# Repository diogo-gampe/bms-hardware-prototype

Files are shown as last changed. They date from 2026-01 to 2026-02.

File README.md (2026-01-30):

## Desenvolvimento em KICAD de placa de avaliação do CI da Texas Instrumets BQ769x2 para monitoramento e proteção de batérias de íon-lítio 3S-16S.

## Changelog

12/12/25
- Separa folha de monitoramento, folha de proteção e folha raiz
- (Folha raiz)Adiciona conector para resistores shunt de simulação de células
- (Folha de monitoramento) Adiciona botão de WAKE no pino TS2 do CI e jumper para conectar termistor externo ao pino TS2
- (Folha de monitoramento) Adiciona conector para monitorar externamente tensões geradas por regulador interno do CI em REG1 e REG2.
- (Folha de proteção) Adiciona componentes para circuito de disparo de fusível controlável
- (Folha de proteção) Adiciona componentes para circuito de pré-carga/descarga
- (Folha de proteção) Adciona componentes para proteção de conexão com polaridade reversa

18/12/25
- Adiciona diretório com simulações de LTSpice
28/01/25
- Adiciona footprints finais, com base na lista de componentes fornecidas ao pessoal do SENAI
- Posiciona Net-Tie entre terminal negativo da bateria e tensão de referência dos CIs para isolar caminhos de alta corrente
30/01/25
- Posiciona footprints de testpoints para medições de sinais chave para testes. 
- Ajusta posicionamento de regiões de alta corrente.

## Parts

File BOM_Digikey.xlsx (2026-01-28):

Reference | Value | Qty | Digikey Link | Manufacturer_Part_Number
 | STM32H745ZIT3 | 5 | https://www.digikey.ca/en/products/detail/stmicroelectronics/STM32H745ZIT3/11591192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 | STM32H745ZIT3
 | BQ76972PFBR | 5 | https://www.digikey.ca/en/products/detail/texas-instruments/BQ7697202PFBR/22077512 | BQ7697202PFBR
U2 | BQ7695202PFBR | 5 | https://www.digikey.ca/en/products/detail/texas-instruments/BQ7695202PFBR/14123974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 | BQ7695202PFBR
 | TJA1044BT/0Z | 5 | https://www.digikey.ca/en/products/detail/nxp-usa-inc/TJA1044BT-0Z/19200494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 | TJA1044BT/0Z
C47 | 100pF | 5 | https://www.digikey.ca/en/products/detail/johanson-dielectrics-inc/VPDD102W101K1GV001E/2236983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 | VPDD102W101K1GV001E
C33 | 100pF | 5 | https://www.digikey.ca/en/products/detail/johanson-dielectrics-inc/VPDD102W101K1GV001E/2236983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 | VPDD102W101K1GV001E
SW1 | SW_DIP_x01 | 5 | https://www.digikey.ca/en/products/detail/adam-tech/SW-T3-1A-A-A3-S1/15284460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 | SW-T3-1A-A-A3-S1
D6 | LED | 5 | https://www.digikey.ca/en/products/detail/lumex-opto-components-inc/SML-LX1210IGC-TR/229144 | SML-LX1210IGC-TR
Q8 | Q_PMOS_GSD | 5 | https://www.digikey.ca/en/products/detail/vishay-siliconix/SI3437DV-T1-GE3/2441596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 | SI3437DV-T1-GE3
Q7 | Q_PMOS_GSD | 5 | https://www.digikey.ca/en/products/detail/vishay-siliconix/SI3437DV-T1-GE3/2441596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 | SI3437DV-T1-GE3
J5 | Conn_02x08_Odd_Even | 5 | https://www.digikey.ca/en/products/detail/sullins-connector-solutions/SBH11-PBPC-D08-ST-BK/1990064 | SBH11-PBPC-D08-ST-BK
R27 | 7.5k | 5 | https://www.digikey.ca/en/products/detail/stackpole-electronics-inc/RNCP1206FTD7K50/2240366 | RNCP1206FTD7K50
R59 | 100 | 5 | https://www.digikey.ca/en/products/detail/yageo/RC1206FR-07100RL/728491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 | RC1206FR-07100RL
R57 | 100 | 5 | https://www.digikey.ca/en/products/detail/yageo/RC1206FR-07100RL/728491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 | RC1206FR-07100RL
R55 | 100 | 5 | https://www.digikey.ca/en/products/detail/yageo/RC1206FR-07100RL/728491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 | RC1206FR-07100RL
R65 | 20 | 5 | https://www.digikey.ca/en/products/detail/yageo/RC1206FR-0720RL/728671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 | RC1206FR-0720RL
R64 | 20 | 5 | https://www.digikey.ca/en/products/detail/yageo/RC1206FR-0720RL/728671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 | RC1206FR-0720RL
R63 | 20 | 5 | https://www.digikey.ca/en/products/detail/yageo/RC1206FR-0720RL/728671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 | RC1206FR-0720RL
R36 | 20 | 5 | https://www.digikey.ca/en/products/detail/yageo/RC1206FR-0720RL/728671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 | RC1206FR-0720RL
R21 | 20 | 5 | https://www.digikey.ca/en/products/detail/yageo/RC1206FR-0720RL/728671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 | RC1206FR-0720RL
R20 | 20 | 5 | https://www.digikey.ca/en/products/detail/yageo/RC1206FR-0720RL/728671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 | RC1206FR-0720RL
R19 | 20 | 5 | https://www.digikey.ca/en/products/detail/yageo/RC1206FR-0720RL/728671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 | RC1206FR-0720RL
R18 | 20 | 5 | https://www.digikey.ca/en/products/detail/yageo/RC1206FR-0720RL/728671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 | RC1206FR-0720RL
R17 | 20 | 5 | https://www.digikey.ca/en/products/detail/yageo/RC1206FR-0720RL/728671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 | RC1206FR-0720RL
R16 | 20 | 5 | https://www.digikey.ca/en/products/detail/yageo/RC1206FR-0720RL/728671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 | RC1206FR-0720RL
R15 | 20 | 5 | https://www.digikey.ca/en/products/detail/yageo/RC1206FR-0720RL/728671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 | RC1206FR-0720RL
R14 | 20 | 5 | https://www.digikey.ca/en/products/detail/yageo/RC1206FR-0720RL/728671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 | RC1206FR-0720RL
R13 | 20 | 5 | https://www.digikey.ca/en/products/detail/yageo/RC1206FR-0720RL/728671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 | RC1206FR-0720RL
R12 | 20 | 5 | https://www.digikey.ca/en/products/detail/yageo/RC1206FR-0720RL/728671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 | RC1206FR-0720RL
R11 | 20 | 5 | https://www.digikey.ca/en/products/detail/yageo/RC1206FR-0720RL/728671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 | RC1206FR-0720RL
SW3 | RST_SHUT | 5 | https://www.digikey.ca/en/products/detail/c-k/PTS526SM15SMTR2-LFS/10056625 | PTS526SM15SMTR2 LFS
SW4 | WAKE | 5 | https://www.digikey.ca/en/products/detail/c-k/PTS526SM15SMTR2-LFS/10056625 | PTS526SK15SMTR2 LFS
J2 | Conn_01x13_Pin | 5 | https://www.digikey.ca/en/products/detail/adam-tech/PH1-13-UA/9830369 | PH1-13-UA
D16 | D_Zener | 5 | https://www.digikey.ca/en/products/detail/onsemi/MMSZ4697T1G/919730 | MMSZ4697T1G
D11 | 16V | 5 | https://www.digikey.ca/en/products/detail/mcc-micro-commercial-components/MMSZ5246B-TP/1793207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 | MMSZ5246B-TP
D9 | 16V | 5 | https://www.digikey.ca/en/products/detail/mcc-micro-commercial-components/MMSZ5246B-TP/1793207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 | MMSZ5246B-TP
D5 | 16V | 5 | https://www.digikey.ca/en/products/detail/mcc-micro-commercial-components/MMSZ5246B-TP/1793207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 | MMSZ5246B-TP
D15 | 100V | 5 | https://www.digikey.ca/en/products/detail/onsemi/MMBD914LT3G/1749014 | MMBD914LT3G
F1 | SCF9550-30-20L | 5 | https://www.digikey.ca/en/products/detail/eaton-electronics-division/SCF9550-30-20L/15973946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 | SCF9550-30-20L
Q5 | Q_NMOS_GSD | 5 | https://www.digikey.ca/en/products/detail/infineon-technologies/IPD200N15N3GATMA1/5334533 | IPD200N15N3GATMA1
Q3 | Q_NMOS_GSD | 5 | https://www.digikey.ca/en/products/detail/infineon-technologies/IPD200N15N3GATMA1/5334533 | IPD200N15N3GATMA1
Q2 | Q_NMOS_GSD | 5 | https://www.digikey.ca/en/products/detail/infineon-technologies/IPD200N15N3GATMA1/5334533 | IPD200N15N3GATMA1
R60 | 10M | 5 | https://www.digikey.ca/en/products/detail/koa-speer-electronics-inc/HV732BTTD1005F/10134470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 | HV732BTTD1005F
R40 | 10M | 5 | https://www.digikey.ca/en/products/detail/koa-speer-electronics-inc/HV732BTTD1005F/10134470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 | HV732BTTD1005F
R37 | 10M | 5 | https://www.digikey.ca/en/products/detail/koa-speer-electronics-inc/HV732BTTD1005F/10134470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 | HV732BTTD1005F
R34 | 10M | 5 | https://www.digikey.ca/en/products/detail/koa-speer-electronics-inc/HV732BTTD1005F/10134470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 | HV732BTTD1005F
R26 | 10M | 5 | https://www.digikey.ca/en/products/detail/koa-speer-electronics-inc/HV732BTTD1005F/10134470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 | HV732BTTD1005F
R22 | 10M | 5 | https://www.digikey.ca/en/products/detail/koa-speer-electronics-inc/HV732BTTD1005F/10134470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 | HV732BTTD1005F
R39 | 2k | 5 | https://www.digikey.ca/en/products/detail/susumu/HRG3216P-2001-D-T1/5762491 | HRG3216P-2001-D-T1
R38 | 2k | 5 | https://www.digikey.ca/en/products/detail/susumu/HRG3216P-2001-D-T1/5762491 | HRG3216P-2001-D-T1
J4 | Conn_01x02_Pin |  | https://www.digikey.ca/en/products/detail/phoenix-contact/1935776/2513905 | 1935776
J3 | Conn_01x02_Pin | 5 | https://www.digikey.ca/en/products/detail/amphenol-cs-commercial-products/G800W306018EU/13683144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 | G800W306018EU
J1 | Conn_02x12_Odd_Even | 5 | https://www.digikey.ca/en/products/detail/amphenol-cs-commercial-products/G800W268018EU/17083164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 | G800W268018EU
R61 | 10k | 5 | https://www.digikey.ca/en/products/detail/panasonic-electronic-components/ERJ-8GEYJ103V/12063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 | ERJ-8GEYJ103V
R58 | 10k | 5 | https://www.digikey.ca/en/products/detail/panasonic-electronic-components/ERJ-8GEYJ103V/12063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 | ERJ-8GEYJ103V
R56 | 10k | 5 | https://www.digikey.ca/en/products/detail/panasonic-electronic-components/ERJ-8GEYJ103V/12063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 | ERJ-8GEYJ103V
R42 | 5.1k | 5 | https://www.digikey.ca/en/products/detail/vishay-dale/CRCW12065K10FKEAHP/2227824 | CRCW12065K10FKEAHP
R41 | 5.1k | 5 | https://www.digikey.ca/en/products/detail/vishay-dale/CRCW12065K10FKEAHP/2227824 | CRCW12065K10FKEAHP
R35 | 5.1k | 5 | https://www.digikey.ca/en/products/detail/vishay-dale/CRCW12065K10FKEAHP/2227824 | CRCW12065K10FKEAHP
R33 | 5.1k | 5 | https://www.digikey.ca/en/products/detail/vishay-dale/CRCW12065K10FKEAHP/2227824 | CRCW12065K10FKEAHP
R32 | 5.1k | 5 | https://www.digikey.ca/en/products/detail/vishay-dale/CRCW12065K10FKEAHP/2227824 | CRCW12065K10FKEAHP
R31 | 5.1k | 5 | https://www.digikey.ca/en/products/detail/vishay-dale/CRCW12065K10FKEAHP/2227824 | CRCW12065K10FKEAHP
R30 | 5.1k | 5 | https://www.digikey.ca/en/products/detail/vishay-dale/CRCW12065K10FKEAHP/2227824 | CRCW12065K10FKEAHP
R29 | 5.1k | 5 | https://www.digikey.ca/en/products/detail/vishay-dale/CRCW12065K10FKEAHP/2227824 | CRCW12065K10FKEAHP
R28 | 5.1k | 5 | https://www.digikey.ca/en/products/detail/vishay-dale/CRCW12065K10FKEAHP/2227824 | CRCW12065K10FKEAHP
R25 | 5.1k | 5 | https://www.digikey.ca/en/products/detail/vishay-dale/CRCW12065K10FKEAHP/2227824 | CRCW12065K10FKEAHP
R24 | 5.1k | 5 | https://www.digikey.ca/en/products/detail/vishay-dale/CRCW12065K10FKEAHP/2227824 | CRCW12065K10FKEAHP
R23 | 5.1k | 5 | https://www.digikey.ca/en/products/detail/vishay-dale/CRCW12065K10FKEAHP/2227824 | CRCW12065K10FKEAHP
R62 | 220 | 5 | https://www.digikey.ca/en/products/detail/susumu/HRG3216P-2200-B-T1/5762493 | HRG3216P-2200-B-T1
R45 | 220 | 5 | https://www.digikey.ca/en/products/detail/susumu/HRG3216P-2200-B-T1/5762493 | CRCW2512220RJNEG
R44 | 220 | 5 | https://www.digikey.ca/en/products/detail/susumu/HRG3216P-2200-B-T1/5762493 | CR1206-FX-2000ELF
R43 | 220 | 5 | https://www.digikey.ca/en/products/detail/susumu/HRG3216P-2200-B-T1/5762493 | CR1206-FX-2000ELF
R10 | 220 | 5 | https://www.digikey.ca/en/products/detail/susumu/HRG3216P-2200-B-T1/5762493 | CR1206-FX-2000ELF
R9 | 220 | 5 | https://www.digikey.ca/en/products/detail/susumu/HRG3216P-2200-B-T1/5762493 | CR1206-FX-2000ELF
R8 | 220 | 5 | https://www.digikey.ca/en/products/detail/susumu/HRG3216P-2200-B-T1/5762493 | CR1206-FX-2000ELF
R7 | 220 | 5 | https://www.digikey.ca/en/products/detail/susumu/HRG3216P-2200-B-T1/5762493 | CR1206-FX-2000ELF
R6 | 220 | 5 | https://www.digikey.ca/en/products/detail/susumu/HRG3216P-2200-B-T1/5762493 | CR1206-FX-2000ELF
R5 | 220 | 5 | https://www.digikey.ca/en/products/detail/susumu/HRG3216P-2200-B-T1/5762493 | CR1206-FX-2000ELF
R4 | 220 | 5 | https://www.digikey.ca/en/products/detail/susumu/HRG3216P-2200-B-T1/5762493 | CR1206-FX-2000ELF
R3 | 220 | 5 | https://www.digikey.ca/en/products/detail/susumu/HRG3216P-2200-B-T1/5762493 | CR1206-FX-2000ELF
R2 | 220 | 5 | https://www.digikey.ca/en/products/detail/susumu/HRG3216P-2200-B-T1/5762493 | CR1206-FX-2000ELF
R1 | 220 | 5 | https://www.digikey.ca/en/products/detail/susumu/HRG3216P-2200-B-T1/5762493 | CR1206-FX-2000ELF
C30 | 0.47uF | 5 | https://www.digikey.ca/en/products/detail/samsung-electro-mechanics/CL31B474KBHNNNE/3886776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 | CL31B474KBHNNNE
C50 | 2.2uF | 5 | https://www.digikey.ca/en/products/detail/samsung-electro-mechanics/CL31B225KBHNNNE/3886949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 | CL31B225KBHNNNE
C52 | 1uF | 5 | https://www.digikey.ca/en/products/detail/samsung-electro-mechanics/CL31B105KBHNNNE/3886726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 | CL31B105KBHNNNE
C51 | 1uF | 5 | https://www.digikey.ca/en/products/detail/samsung-electro-mechanics/CL31B105KBHNNNE/3886726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 | CL31B105KBHNNNE
C49 | 1uF | 5 | https://www.digikey.ca/en/products/detail/samsung-electro-mechanics/CL31B105KBHNNNE/3886726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 | CL31B105KBHNNNE
C31 | 1uF | 5 | https://www.digikey.ca/en/products/detail/samsung-electro-mechanics/CL31B105KBHNNNE/3886726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 | CL31B105KBHNNNE
C53 | 22nF | 5 | https://www.digikey.ca/en/products/detail/yageo/CC1206JRNPO9BN223/20376269 | CC1206JRNPO9BN223
C13 | 220nF | 5 | https://www.digikey.ca/en/products/detail/kemet/C1206C224J5RECAUTO/8646922 | C1206C224J5RECAUTO
C12 | 220nF | 5 | https://www.digikey.ca/en/products/detail/kemet/C1206C224J5RECAUTO/8646922 | C1206C224J5RECAUTO
C11 | 220nF | 5 | https://www.digikey.ca/en/products/detail/kemet/C1206C224J5RECAUTO/8646922 | C1206C224J5RECAUTO
C10 | 220nF | 5 | https://www.digikey.ca/en/products/detail/kemet/C1206C224J5RECAUTO/8646922 | C1206C224J5RECAUTO
C9 | 220nF | 5 | https://www.digikey.ca/en/products/detail/kemet/C1206C224J5RECAUTO/8646922 | C1206C224J5RECAUTO
C8 | 220nF | 5 | https://www.digikey.ca/en/products/detail/kemet/C1206C224J5RECAUTO/8646922 | C1206C224J5RECAUTO
C7 | 220nF | 5 | https://www.digikey.ca/en/products/detail/kemet/C1206C224J5RECAUTO/8646922 | C1206C224J5RECAUTO
C6 | 220nF | 5 | https://www.digikey.ca/en/products/detail/kemet/C1206C224J5RECAUTO/8646922 | C1206C224J5RECAUTO
C5 | 220nF | 5 | https://www.digikey.ca/en/products/detail/kemet/C1206C224J5RECAUTO/8646922 | C1206C224J5RECAUTO
C4 | 220nF | 5 | https://www.digikey.ca/en/products/detail/kemet/C1206C224J5RECAUTO/8646922 | C1206C224J5RECAUTO
C3 | 220nF | 5 | https://www.digikey.ca/en/products/detail/kemet/C1206C224J5RECAUTO/8646922 | C1206C224J5RECAUTO
C2 | 220nF | 5 | https://www.digikey.ca/en/products/detail/kemet/C1206C224J5RECAUTO/8646922 | C1206C224J5RECAUTO
C1 | 220nF | 5 | https://www.digikey.ca/en/products/detail/kemet/C1206C224J5RECAUTO/8646922 | C1206C224J5RECAUTO
C48 | 0.1uF | 5 | https://www.digikey.ca/en/products/detail/kemet/C1206C104K5RACTU/411248 | C1206C104K5RACTU
C29 | 0.1uF | 5 | https://www.digikey.ca/en/products/detail/kemet/C1206C104K5RACTU/411248 | C1206C104K5RACTU
C28 | 0.1uF | 5 | https://www.digikey.ca/en/products/detail/kemet/C1206C104K5RACTU/411248 | C1206C104K5RACTU
C27 | 0.1uF | 5 | https://www.digikey.ca/en/products/detail/kemet/C1206C104K5RACTU/411248 | C1206C104K5RACTU
C26 | 0.1uF | 5 | https://www.digikey.ca/en/products/detail/kemet/C1206C104K5RACTU/411248 | C1206C104K5RACTU
C25 | 0.1uF | 5 | https://www.digikey.ca/en/products/detail/kemet/C1206C104K5RACTU/411248 | C1206C104K5RACTU
D12 | 100V | 5 | https://www.digikey.ca/en/products/detail/diodes-incorporated/BAT46W-7-F/1934440 | BAT46W-7-F
D7 | 100V | 5 | https://www.digikey.ca/en/products/detail/diodes-incorporated/BAT46W-7-F/1934440 | BAT46W-7-F
D4 | 100V | 5 | https://www.digikey.ca/en/products/detail/diodes-incorporated/BAT46W-7-F/1934440 | BAT46W-7-F
D3 | 100V | 5 | https://www.digikey.ca/en/products/detail/diodes-incorporated/BAT46W-7-F/1934440 | BAT46W-7-F
D2 | 100V | 5 | https://www.digikey.ca/en/products/detail/diodes-incorporated/BAT46W-7-F/1934440 | BAT46W-7-F
D1 | 100V | 5 | https://www.digikey.ca/en/products/detail/diodes-incorporated/BAT46W-7-F/1934440 | BAT46W-7-F
Q4 | Q_NMOS_GSD | 5 | https://www.digikey.ca/en/products/detail/alpha-omega-semiconductor-inc/AOD256/3603541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 | AOD256
Q6 | NPN | 5 | https://www.digikey.ca/en/products/detail/rochester-electronics-llc/2N5830/11523351 | 2N5830
J7 | Conn_01x03_Pin | 5 | https://www.digikey.ca/en/products/detail/oupiin/2011-1X03G00SB-1/24712611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 | 2011-1X03G00SB-1
C46 | 0.01uF | 5 | https://www.digikey.ca/en/products/detail/kyocera-avx/1206PC103KAT2A/11208980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 | 1206PC103KAT2A
TH4 | Thermistor | 5 | https://www.digikey.ca/en/products/detail/semitec-usa-corp/103AT-2/16579059?s=N4IgTCBcDaIIwAYDMBBAKgWggXQL5A | 103AT-2
TH3 | Thermistor | 5 | https://www.digikey.ca/en/products/detail/semitec-usa-corp/103AT-2/16579059?s=N4IgTCBcDaIIwAYDMBBAKgWggXQL5A | 103AT-2
Rsense1 | 0.001 | 5

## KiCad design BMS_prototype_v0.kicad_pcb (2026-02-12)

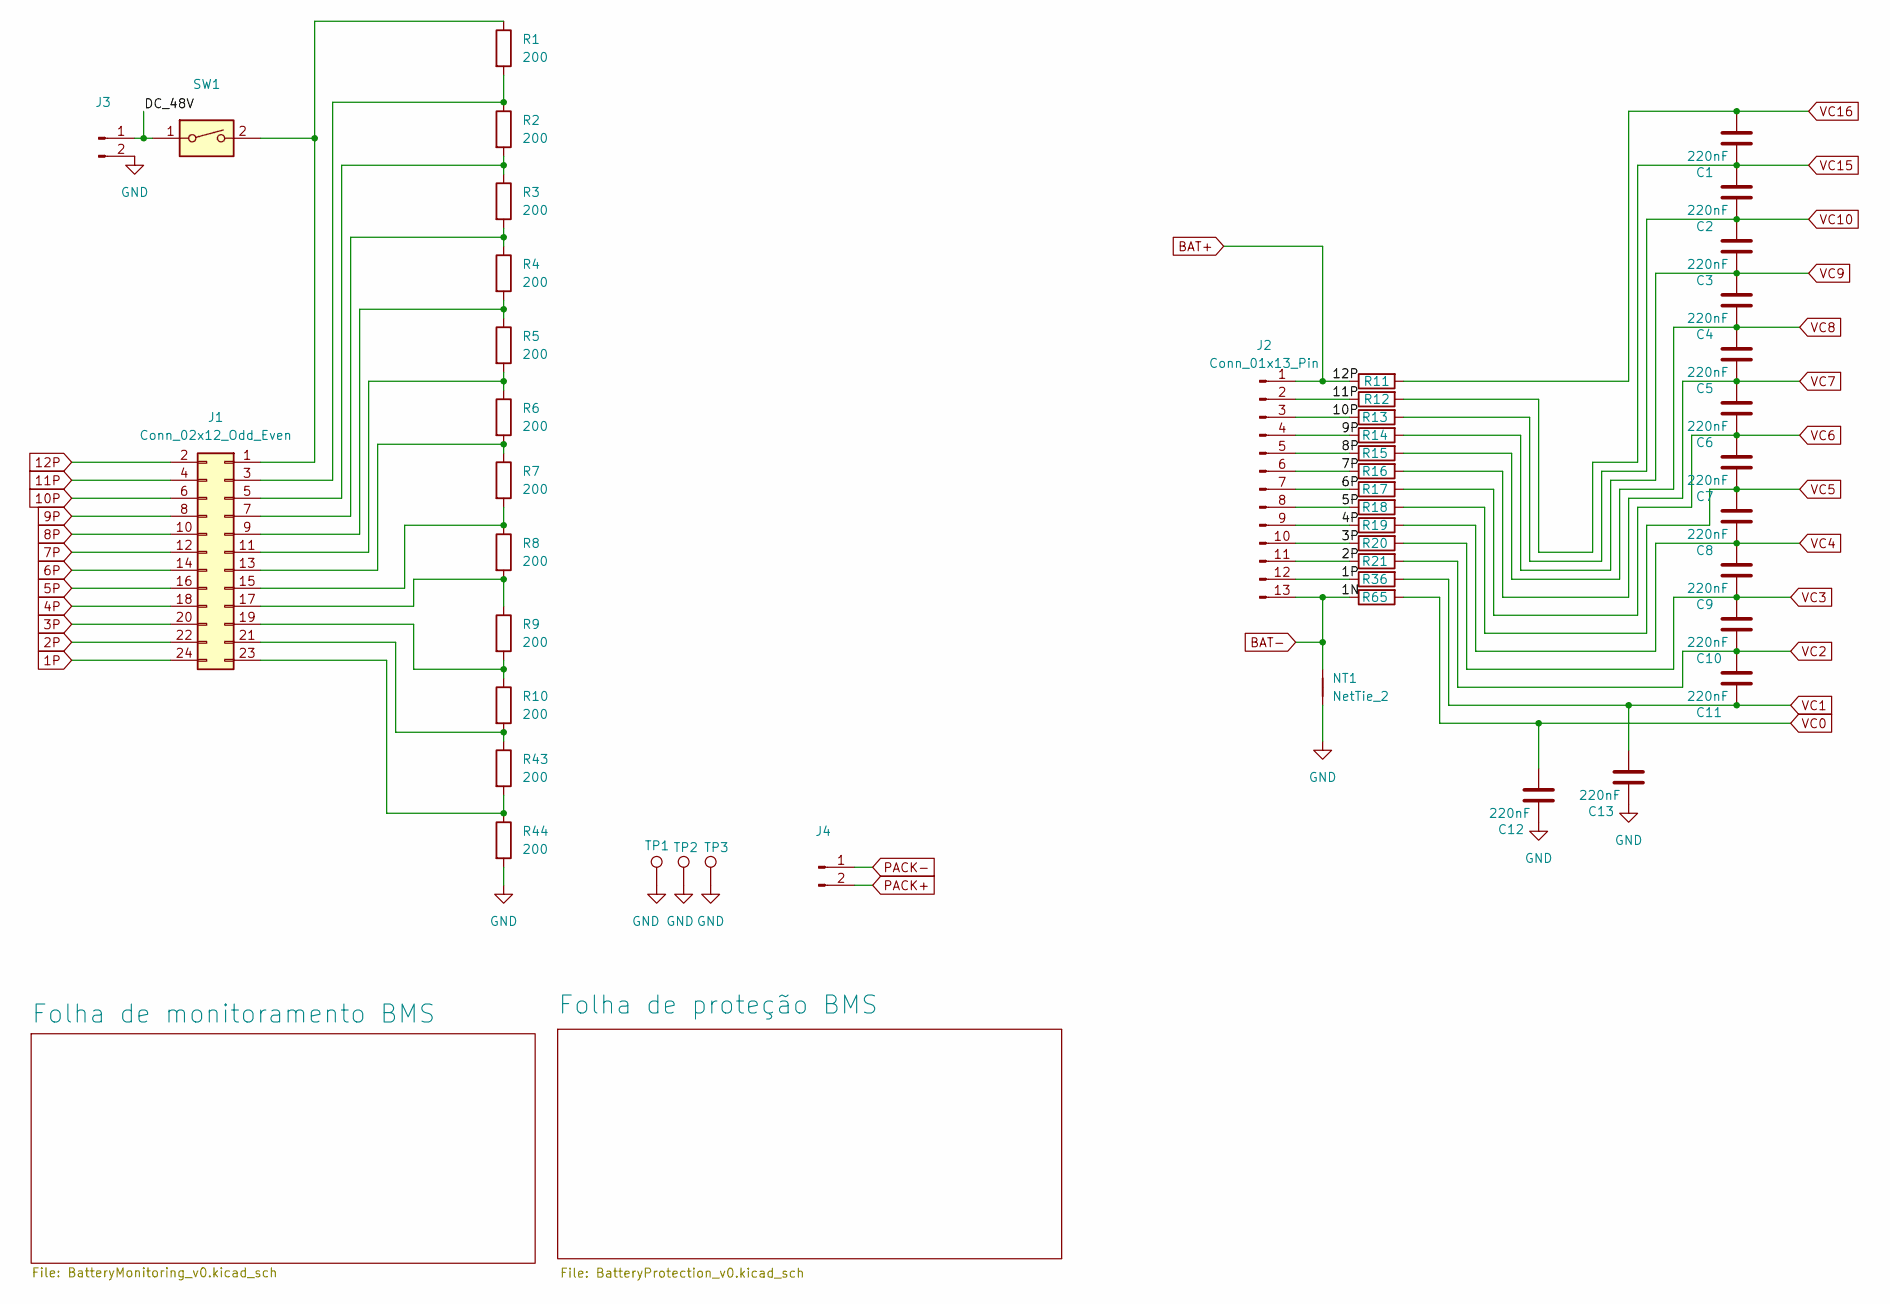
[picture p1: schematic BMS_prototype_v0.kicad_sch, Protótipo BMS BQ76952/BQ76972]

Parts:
C1, C2, C3, C4, C5, C6, C7, C8, C9, C10, C11, C12, C13: 220nF; C_1206_3216Metric_Pad1.33x1.80mm_HandSolder; Manufacturer_Part_Number C1206C224J5RECAUTO
J1: Conn_02x12_Odd_Even; PinHeader_2x12_P2.54mm_Vertical; Manufacturer_Part_Number G800W268018EU
J2: Conn_01x13_Pin; PinHeader_1x13_P2.54mm_Vertical; Manufacturer_Part_Number PH1-13-UA
J3: Conn_01x02_Pin; PinHeader_1x02_P2.54mm_Vertical; Manufacturer_Part_Number G800W306018EU
J4: Conn_01x02_Pin; CONN_1935776_PXC; Manufacturer_Part_Number G800W306018EU
NT1: NetTie_2; NetTie-2_SMD_Pad0.5mm
R1, R2, R3, R4, R5, R6, R7, R8, R9, R10, R43, R44: 200; R_1206_3216Metric; Manufacturer_Part_Number CR1206-FX-2000ELF
R11, R12, R13, R14, R15, R16, R17, R18, R19, R20, R21, R36, R65: 20; R_1206_3216Metric; Manufacturer_Part_Number RC1206FR-0720RL
SW1: SW_DIP_x01; SWT31AAA3S1; Manufacturer_Part_Number SW-T3-1A-A-A3-S1
TP1, TP2, TP3: TestPoint; TestPoint_Pad_3.0x3.0mm

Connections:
1P: J1.24, J2.12, R36.1
2P: J1.22, J2.11, R21.1
3P: J1.20, J2.10, R20.1
4P: J1.18, J2.9, R19.1
5P: J1.16, J2.8, R18.1
6P: J1.14, J2.7, R17.1
7P: J1.12, J2.6, R16.1
8P: J1.10, J2.5, R15.1
9P: J1.8, J2.4, R14.1
10P: J1.6, J2.3, R13.1
11P: J1.4, J2.2, R12.1
12P: J1.2, J2.1, R11.1; also elsewhere on the board
/DC_48V: J3.1, SW1.1
BAT-: J2.13, NT1.2, R65.1; also elsewhere on the board
GND: C12.2, C13.2, J3.2, NT1.1, R44.2, TP1.1, TP2.1, TP3.1; also elsewhere on the board
unnamed: J1.1, R1.1, SW1.2
unnamed: J1.3, R1.2, R2.1
unnamed: J1.5, R2.2, R3.1
unnamed: J1.7, R3.2, R4.1
unnamed: J1.9, R4.2, R5.1
unnamed: J1.11, R5.2, R6.1
unnamed: J1.13, R6.2, R7.1
unnamed: J1.15, R7.2, R8.1
unnamed: J1.17, R8.2, R9.1
unnamed: J1.19, R9.2, R10.1
unnamed: J1.21, R10.2, R43.1
unnamed: J1.23, R43.2, R44.1
PACK+: J4.2; also elsewhere on the board
PACK-: J4.1; also elsewhere on the board
VC0: C12.1, R65.2; also elsewhere on the board
VC1: C11.2, C13.1, R36.2; also elsewhere on the board
VC2: C10.2, C11.1, R21.2; also elsewhere on the board
VC3: C9.2, C10.1, R20.2; also elsewhere on the board
VC4: C8.2, C9.1, R19.2; also elsewhere on the board
VC5: C7.2, C8.1, R18.2; also elsewhere on the board
VC6: C6.2, C7.1, R17.2; also elsewhere on the board
VC7: C5.2, C6.1, R16.2; also elsewhere on the board
VC8: C4.2, C5.1, R15.2; also elsewhere on the board
VC9: C3.2, C4.1, R14.2; also elsewhere on the board
VC10: C2.2, C3.1, R13.2; also elsewhere on the board
VC15: C1.2, C2.1, R12.2; also elsewhere on the board
VC16: C1.1, R11.2; also elsewhere on the board

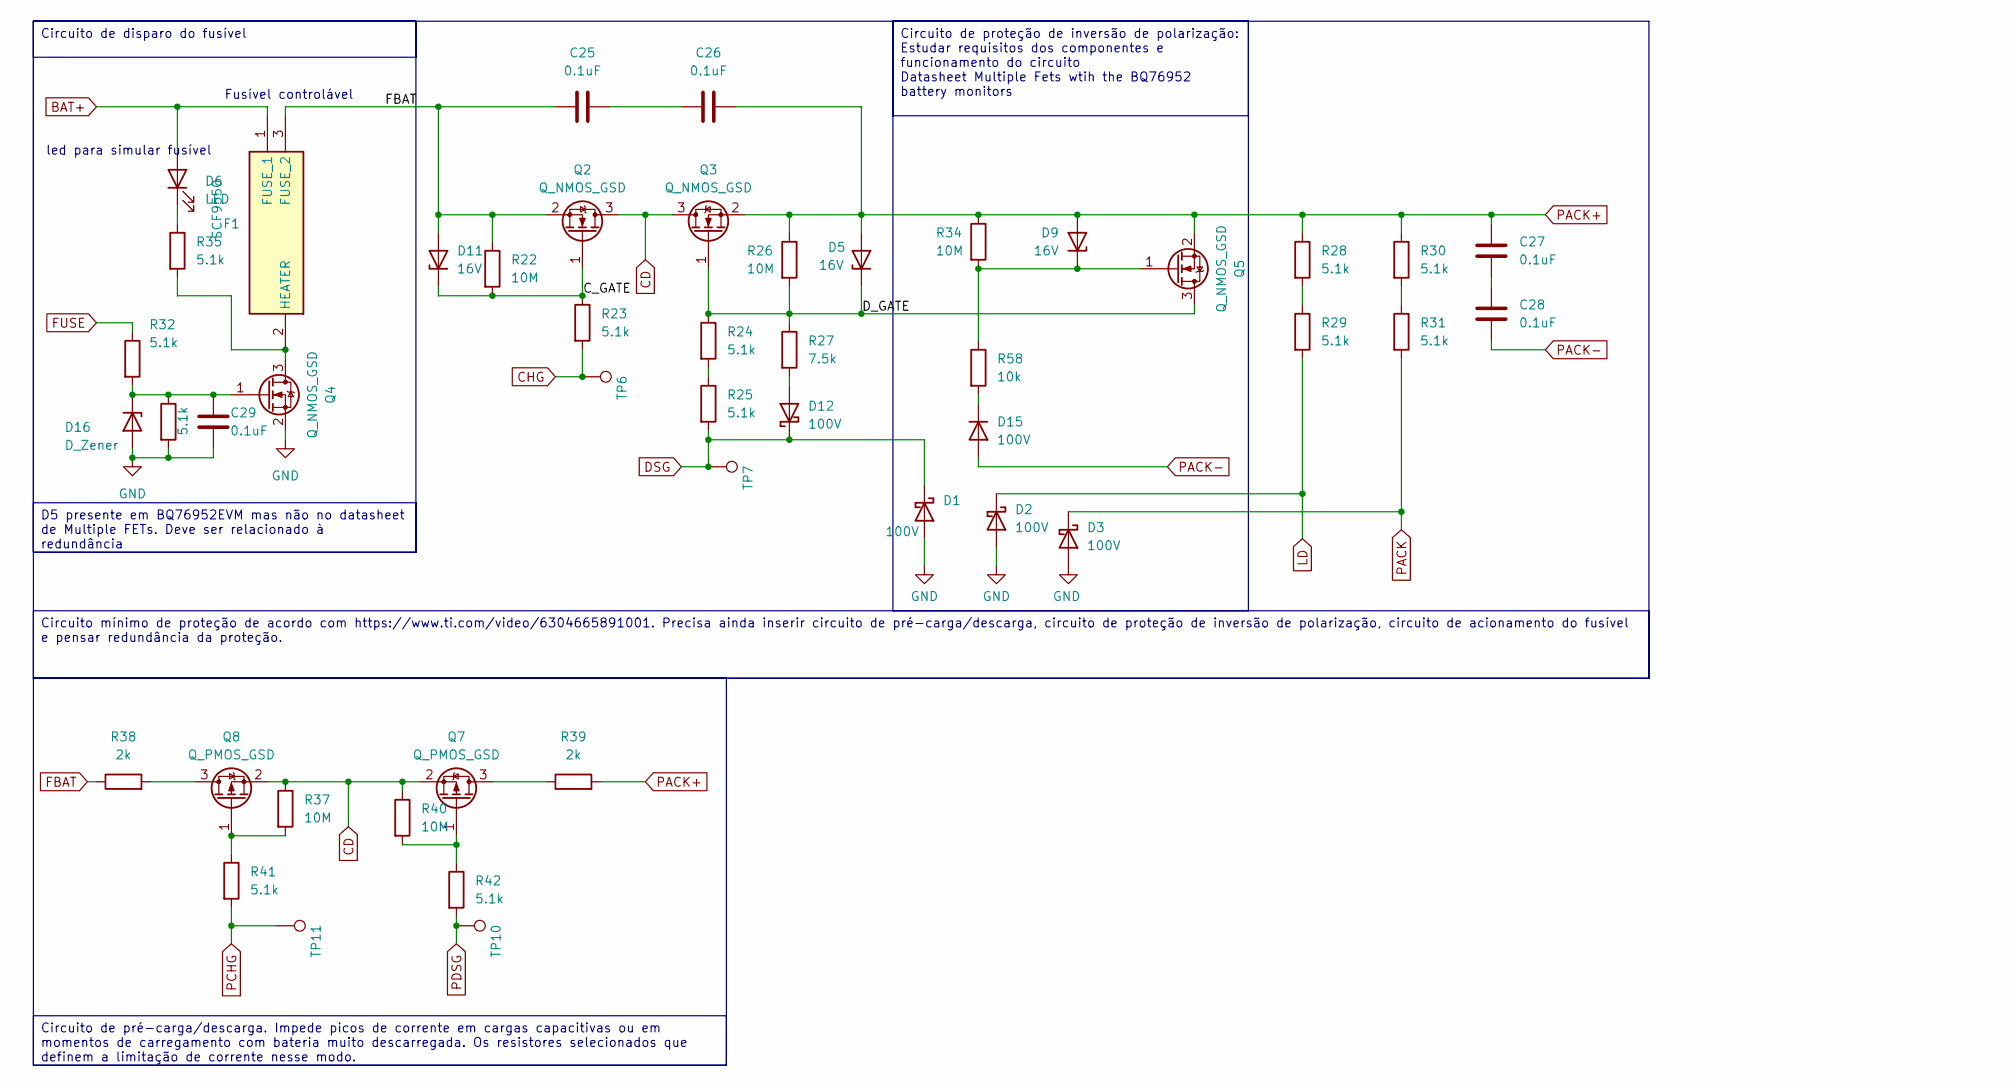
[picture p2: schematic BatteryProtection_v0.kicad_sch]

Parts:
C25, C26, C27, C28, C29: 0.1uF; C_1206_3216Metric_Pad1.33x1.80mm_HandSolder; Manufacturer_Part_Number C1206C104K5RACTU
D1, D2, D3, D12: 100V; D_SOD-123; Manufacturer_Part_Number BAT46W-7-F
D5, D9, D11: 16V; D_SOD-123; Manufacturer_Part_Number MMSZ5246B-TP
D6: LED; LED_1210_3225Metric; Manufacturer_Part_Number SML-LX1210IGC-TR
D15: 100V; SOT-23; Manufacturer_Part_Number MMBD914LT3G
D16: D_Zener; D_SOD-123; Manufacturer_Part_Number MMSZ4697T1G
F1: SCF9550; Sem título; Mouser Part Number 650-ITV4030L1412NR
Q2, Q3, Q5: Q_NMOS_GSD; TO-252-3_TabPin2; Manufacturer_Part_Number IPD200N15N3GATMA1
Q4: Q_NMOS_GSD; TO-252-3_TabPin2; Manufacturer_Part_Number AOD256
Q7, Q8: Q_PMOS_GSD; TSOP-6_1.65x3.05mm_P0.95mm; Manufacturer_Part_Number SI3437DV-T1-GE3
R22, R26, R34, R37, R40: 10M; R_1206_3216Metric; Manufacturer_Part_Number HV732BTTD1005F
R23, R24, R25, R28, R29, R30, R31, R32, R33, R35, R41, R42: 5.1k; R_1206_3216Metric; Manufacturer_Part_Number CRCW12065K10FKEAHP
R27: 7.5k; R_1206_3216Metric; Manufacturer_Part_Number RNCP1206FTD7K50
R38, R39: 2k; R_1206_3216Metric; Manufacturer_Part_Number HRG3216P-2001-D-T1
R58: 10k; R_1206_3216Metric; Manufacturer_Part_Number ERJ-8GEYJ103V
TP6, TP7, TP10, TP11: TestPoint; TestPoint_Loop_D3.80mm_Drill2.5mm

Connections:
12P: D6.2 (A), F1.1 (FUSE_1); also elsewhere on the board
/Folha de proteção BMS/C_GATE: D11.1 (K), Q2.1 (G), R22.2, R23.1
/Folha de proteção BMS/D_GATE: D5.1 (K), Q3.1 (G), Q5.3 (D), R24.1, R26.2, R27.1
CD: Q2.3 (D), Q3.3 (D), Q7.2 (S), Q8.2 (S), R37.1, R40.1; also elsewhere on the board
CHG: R23.2, TP6.1; also elsewhere on the board
DSG: D1.1 (K), D12.1 (K), R25.2, TP7.1; also elsewhere on the board
FBAT: C25.1, D11.2 (A), F1.3 (FUSE_2), Q2.2 (S), R22.1, R38.1
FUSE: R32.1; also elsewhere on the board
GND: C29.1, D1.2 (A), D2.2 (A), D3.2 (A), D16.2 (A), Q4.2 (S), R33.2; also elsewhere on the board
LD: D2.1 (K), R29.2; also elsewhere on the board
unnamed: C25.2, C26.1
unnamed: C27.1, C28.2
unnamed: D6.1 (K), R35.1
unnamed: D9.1 (K), Q5.1 (G), R34.2, R58.1
unnamed: D12.2 (A), R27.2
unnamed: D15.1 (K), R58.2
unnamed: C29.2, D16.1 (K), Q4.1 (G), R32.2, R33.1
unnamed: F1.2 (HEATER), Q4.3 (D), R35.2
unnamed: Q7.3 (D), R39.1
unnamed: Q7.1 (G), R40.2, R42.1
unnamed: Q8.3 (D), R38.2
unnamed: Q8.1 (G), R37.2, R41.1
unnamed: R24.2, R25.1
unnamed: R28.2, R29.1
unnamed: R30.2, R31.1
PACK: D3.1 (K), R31.2; also elsewhere on the board
PACK+: C26.2, C27.2, D5.2 (A), D9.2 (A), Q3.2 (S), Q5.2 (S), R26.1, R28.1, R30.1, R34.1, R39.2; also elsewhere on the board
PACK-: C28.1, D15.2 (A); also elsewhere on the board
PCHG: R41.2, TP11.1; also elsewhere on the board
PDSG: R42.2, TP10.1; also elsewhere on the board

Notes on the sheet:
led para simular fusível
Fusível controlável
Circuito de proteção de inversão de polarização: Estudar requisitos dos componentes e funcionamento do circuito Datasheet Multiple Fets wtih the BQ76952 battery monitors
Circuito mínimo de proteção de acordo com https://www.ti.com/video/6304665891001. Precisa ainda inserir circuito de pré-carga/descarga, circuito de proteção de inversão de polarização, circuito de acionamento do fusível e pensar redundância da proteção.
D5 presente em BQ76952EVM mas não no datasheet de Multiple FETs. Deve ser relacionado à redundância
Circuito de disparo do fusível
Circuito de pré-carga/descarga. Impede picos de corrente em cargas capacitivas ou em momentos de carregamento com bateria muito descarregada. Os resistores selecionados que definem a limitação de corrente nesse modo.

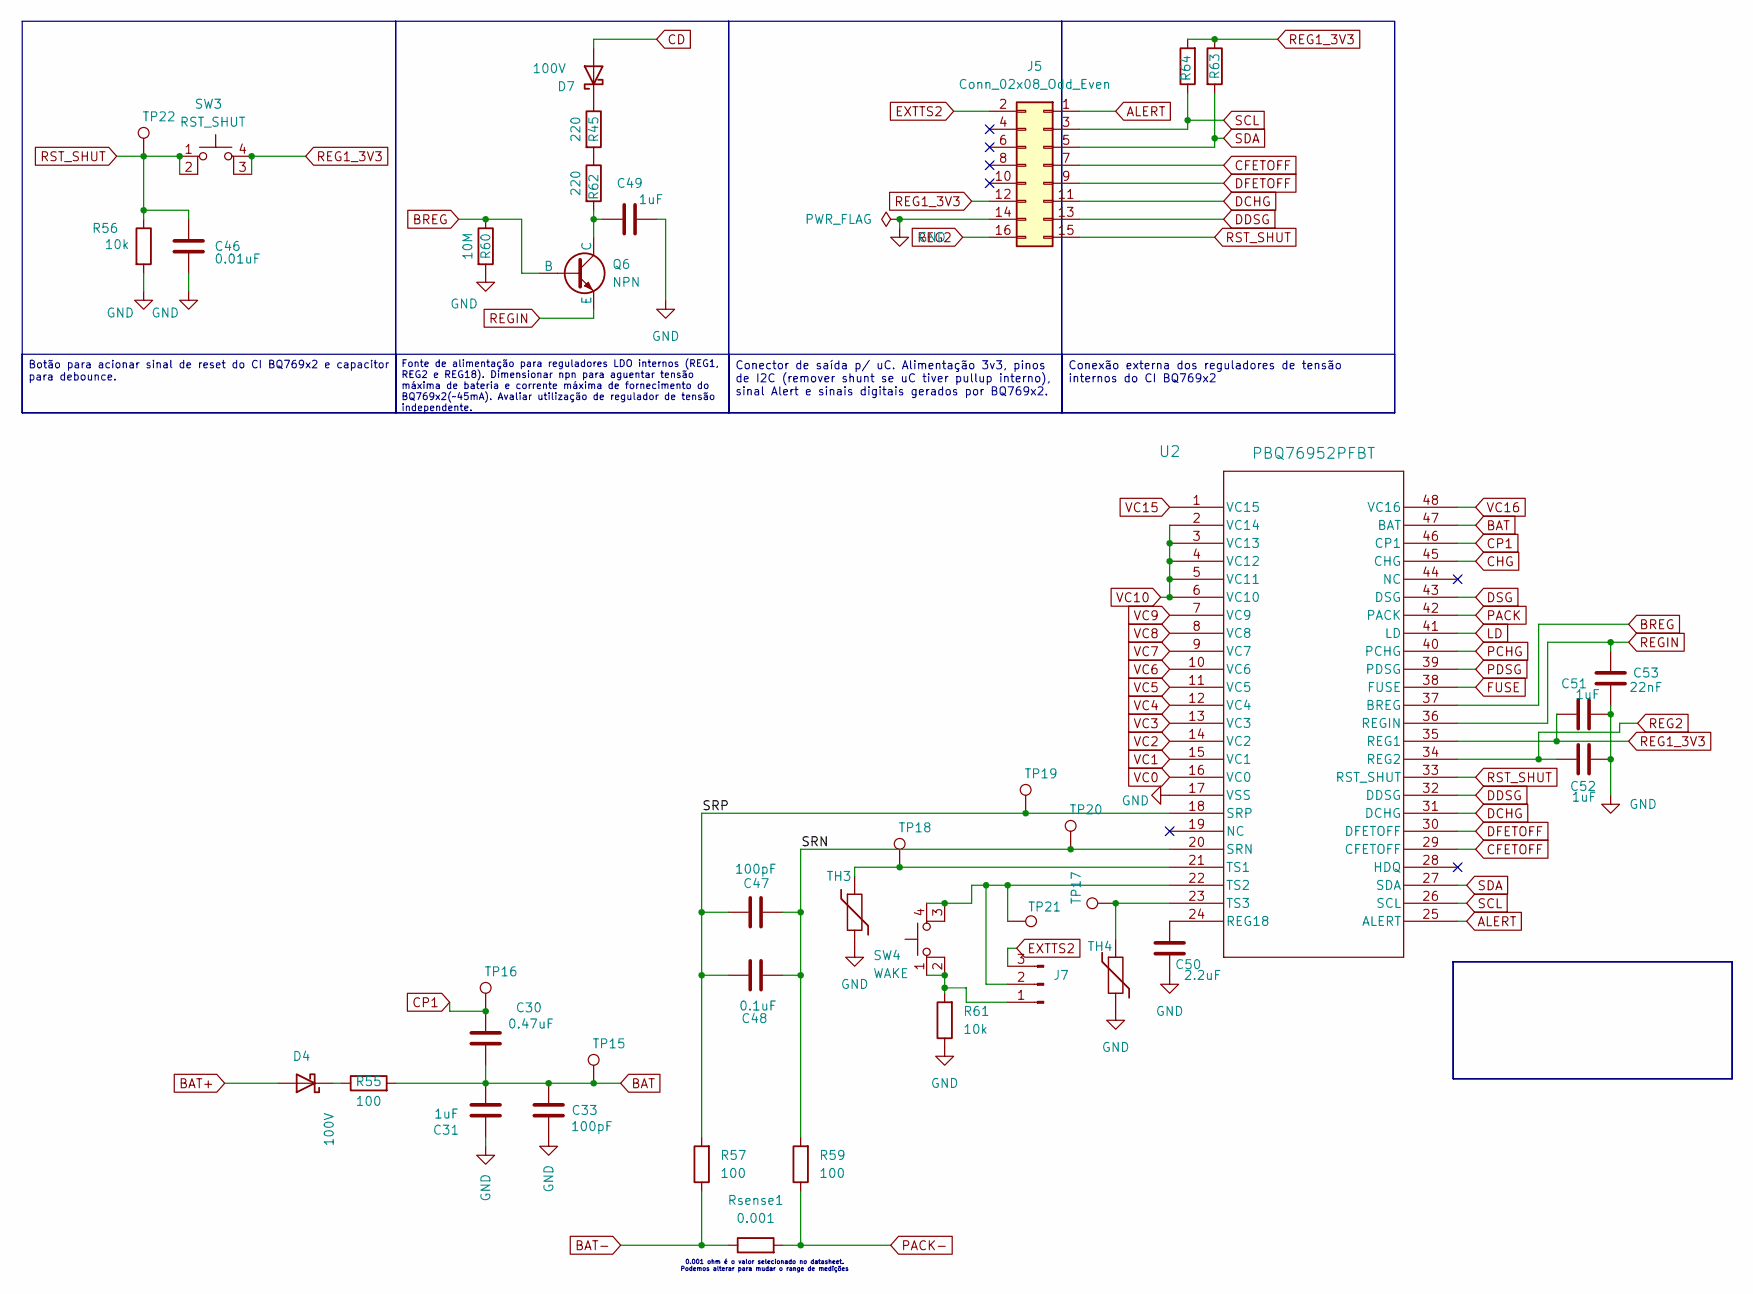
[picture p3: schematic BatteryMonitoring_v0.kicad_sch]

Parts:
C30: 0.47uF; C_1206_3216Metric_Pad1.33x1.80mm_HandSolder; Manufacturer_Part_Number CL31B474KBHNNNE
C31, C49, C51, C52: 1uF; C_1206_3216Metric_Pad1.33x1.80mm_HandSolder; Manufacturer_Part_Number CL31B105KBHNNNE
C33, C47: 100pF; C_1206_3216Metric_Pad1.33x1.80mm_HandSolder; Manufacturer_Part_Number VPDD102W101K1GV001E
C46: 0.01uF; C_1206_3216Metric_Pad1.33x1.80mm_HandSolder; Manufacturer_Part_Number 1206PC103KAT2A
C48: 0.1uF; C_1206_3216Metric_Pad1.33x1.80mm_HandSolder; Manufacturer_Part_Number C1206C104K5RACTU
C50: 2.2uF; C_1206_3216Metric_Pad1.33x1.80mm_HandSolder; Manufacturer_Part_Number CL31B225KBHNNNE
C53: 22nF; C_1206_3216Metric_Pad1.33x1.80mm_HandSolder; Manufacturer_Part_Number CC1206JRNPO9BN223
D4, D7: 100V; D_SOD-123; Manufacturer_Part_Number BAT46W-7-F
J5: Conn_02x08_Odd_Even; CONN16_SBH11-PBPC-D08-ST-BK_SUL; Manufacturer_Part_Number SBH11-PBPC-D08-ST-BK
J7: Conn_01x03_Pin; PinSocket_1x03_P2.54mm_Vertical; Manufacturer_Part_Number 2011-1X03G00SB-1
Q6: NPN; TO-92; Manufacturer_Part_Number 2N5830
R45, R62: 220; R_1206_3216Metric; Manufacturer_Part_Number CRCW2512220RJNEG
R55, R57, R59: 100; R_1206_3216Metric; Manufacturer_Part_Number RC1206FR-07100RL
R56, R61: 10k; R_1206_3216Metric; Manufacturer_Part_Number ERJ-8GEYJ103V
R60: 10M; R_1206_3216Metric; Manufacturer_Part_Number HV732BTTD1005F
R63, R64: 20; R_1206_3216Metric; Manufacturer_Part_Number RC1206FR-0720RL
Rsense1: 0.001; S200_75
SW3: RST_SHUT; SMT_FS; Manufacturer_Part_Number PTS526SM15SMTR2 LFS
SW4: WAKE; SMT_FS; Manufacturer_Part_Number PTS526SK15SMTR2 LFS
TH3, TH4: Thermistor; 103AT2; Manufacturer_Part_Number 103AT-2
TP15, TP16, TP17, TP18, TP19, TP20, TP21, TP22: TestPoint; TestPoint_Loop_D3.80mm_Drill2.5mm
U2: PBQ76952PFBT; BQ7692_TEX; Manufacturer_Part_Number BQ7695202PFBR

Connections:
12P: D4.2 (A); also elsewhere on the board
/Folha de monitoramento BMS/SRN: C47.2, C48.2, R59.2, TP20.1, U2.20 (SRN)
/Folha de monitoramento BMS/SRP: C47.1, C48.1, R57.2, TP19.1, U2.18 (SRP)
ALERT: J5.1, U2.25 (ALERT)
BAT: C30.2, C31.1, C33.1, R55.2, TP15.1, U2.47 (BAT)
BAT-: R57.1, Rsense1.1; also elsewhere on the board
BREG: Q6.2 (B), R60.1, U2.37 (BREG)
CD: D7.2 (A); also elsewhere on the board
CFETOFF: J5.7, U2.29 (CFETOFF)
CHG: U2.45 (CHG); also elsewhere on the board
CP1: C30.1, TP16.1, U2.46 (CP1)
DCHG: J5.11, U2.31 (DCHG)
DDSG: J5.13, U2.32 (DDSG)
DFETOFF: J5.9, U2.30 (DFETOFF)
DSG: U2.43 (DSG); also elsewhere on the board
EXTTS2: J5.2, J7.3
FUSE: U2.38 (FUSE); also elsewhere on the board
GND: C31.2, C33.2, C46.2, C49.2, C50.1, C51.1, C52.1, C53.2, J5.14, R56.2, R60.2, R61.1, TH3.2, TH4.2, U2.17 (VSS); also elsewhere on the board
LD: U2.41 (LD); also elsewhere on the board
unnamed: D4.1 (K), R55.1
unnamed: D7.1 (K), R45.1
unnamed: J7.1, R61.2, SW4.1, SW4.2
unnamed: J7.2, SW4.3 (K), SW4.4 (A), TP21.1, U2.22 (TS2)
unnamed: C49.1, Q6.1 (C), R62.2
unnamed: R45.2, R62.1
unnamed: C50.2, U2.24 (REG18)
unnamed: TH3.1, TP18.1, U2.21 (TS1)
unnamed: TH4.1, TP17.1, U2.23 (TS3)
PACK: U2.42 (PACK); also elsewhere on the board
PACK-: R59.1, Rsense1.2; also elsewhere on the board
PCHG: U2.40 (PCHG); also elsewhere on the board
PDSG: U2.39 (PDSG); also elsewhere on the board
REG1_3V3: C51.2, J5.12, R63.1, R64.2, SW3.3 (K), SW3.4 (A), U2.35 (REG1)
REG2: C52.2, J5.16, U2.34 (REG2)
REGIN: C53.1, Q6.3 (E), U2.36 (REGIN)
RST_SHUT: C46.1, J5.15, R56.1, SW3.1, SW3.2, TP22.1, U2.33 (RST_SHUT)
SCL: J5.3, R64.1, U2.26 (SCL)
SDA: J5.5, R63.2, U2.27 (SDA)
VC0: U2.16 (VC0); also elsewhere on the board
VC1: U2.15 (VC1); also elsewhere on the board
VC2: U2.14 (VC2); also elsewhere on the board
VC3: U2.13 (VC3); also elsewhere on the board
VC4: U2.12 (VC4); also elsewhere on the board
VC5: U2.11 (VC5); also elsewhere on the board
VC6: U2.10 (VC6); also elsewhere on the board
VC7: U2.9 (VC7); also elsewhere on the board
VC8: U2.8 (VC8); also elsewhere on the board
VC9: U2.7 (VC9); also elsewhere on the board
VC10: U2.2 (VC14), U2.3 (VC13), U2.4 (VC12), U2.5 (VC11), U2.6 (VC10); also elsewhere on the board
VC15: U2.1 (VC15); also elsewhere on the board
VC16: U2.48 (VC16); also elsewhere on the board

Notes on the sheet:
0.001 ohm é o valor selecionado no datasheet. Podemos alterar para mudar o range de medições
Conector de saída p/ uC. Alimentação 3v3, pinos de I2C (remover shunt se uC tiver pullup interno), sinal Alert e sinais digitais gerados por BQ769x2.
Botão para acionar sinal de reset do CI BQ769x2 e capacitor para debounce.
Conexão externa dos reguladores de tensão internos do CI BQ769x2
Fonte de alimentação para reguladores LDO internos (REG1, REG2 e REG18). Dimensionar npn para aguentar tensão máxima de bateria e corrente máxima de fornecimento do BQ769x2(~45mA). Avaliar utilização de regulador de tensão independente.

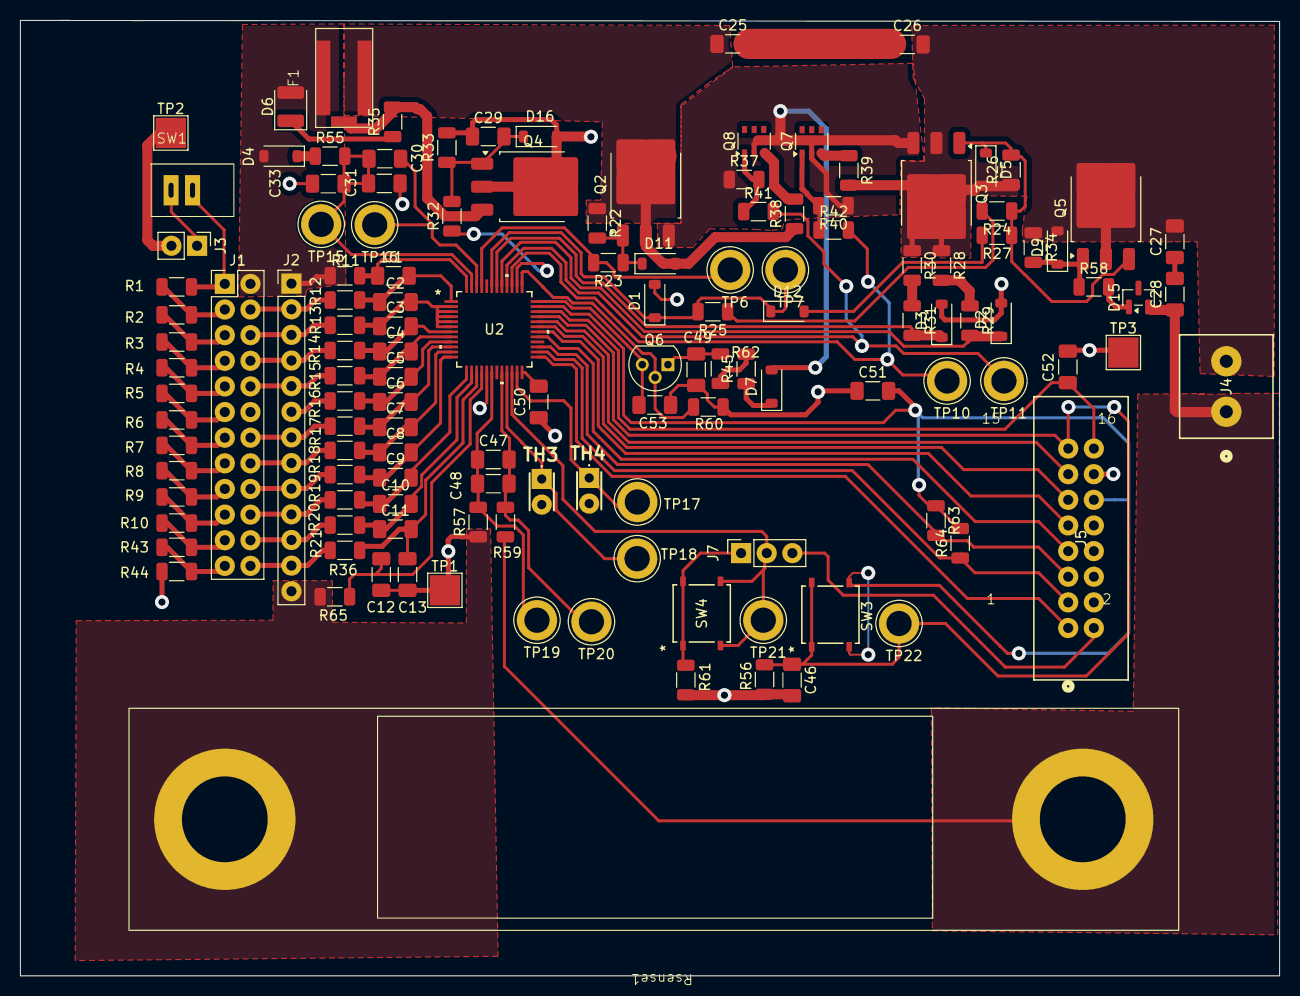
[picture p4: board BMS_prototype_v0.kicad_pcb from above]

Board: 2 copper layers, 124.8 x 94.7 mm, 134 parts (0 on the bottom side), 94 nets.

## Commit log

2025-12-04 add readme
    [BMS_prototype_v0.kicad_pcb, BMS_prototype_v0.kicad_sch, BatteryProtection_v0.kicad_sch]
2025-12-05 Revisão de conexões
    [BMS_prototype_v0.kicad_sch]
2025-12-08 Revisão
    [BMS_prototype_v0.kicad_sch]
2025-12-08 Inserindo footprints
    [BMS_prototype_v0.kicad_sch]
2025-12-10 adiciona folha do esquemático de proteção
    [BMS_prototype_v0.kicad_sch, BatteryProtection_v0.kicad_sch]
2025-12-10 add esquemático de proteção
2025-12-12 adiciona folha de monitoramento, circuitos de protecao
    [BatteryMonitoring_v0.kicad_sch]
2025-12-18 add diretorio de simulações
    [BMS_prototype_v0.kicad_sch, BatteryMonitoring_v0.kicad_sch, BatteryProtection_v0.kicad_sch]
2026-01-13 add simulacao de carga/descarga
2026-01-20 Inicio do roteamento e posicionamento da PCB
    [BMS_prototype_v0.kicad_pcb, BMS_prototype_v0.kicad_sch, BatteryMonitoring_v0.kicad_sch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]
2026-01-22 add Res Shunt e atualiza para Kicad 9.0
    [BMS_prototype_v0.kicad_pcb, BMS_prototype_v0.kicad_sch, BatteryMonitoring_v0.kicad_sch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]
2026-01-23 Troca trilhas por regiões
    [BMS_prototype_v0.kicad_pcb, BatteryMonitoring_v0.kicad_sch]
2026-01-28 Layout com footprints dos componentes da lista
    [BMS_prototype_v0.csv, BMS_prototype_v0.kicad_pcb, BMS_prototype_v0.kicad_sch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]
2026-01-28 layout final de componentes, com footprints da lista de componentes
2026-01-28 layout final de componentes, com footprints da lista de componentes mais uma adição de via GND
    [BMS_prototype_v0.kicad_pcb]
2026-01-30 posiciona testpoints
    [BMS_prototype_v0.csv, BMS_prototype_v0.kicad_pcb, BMS_prototype_v0.kicad_sch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]
2026-02-09 Ajustes no layout do BMS
    [BMS_prototype_v0.kicad_pcb]
2026-02-12 salva 12/02
    [BMS_prototype_v0.kicad_pcb]
